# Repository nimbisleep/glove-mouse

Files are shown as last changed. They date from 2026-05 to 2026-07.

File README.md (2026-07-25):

#  Glove Mouse — Wireless Gesture-Controlled HID

**Graduation Project (Bitirme)** — Düzce University, EEE Department

A wireless glove mouse controlled by hand gestures. Uses an **ESP32** with **MPU6050 IMU (DMP)** for drift-free cursor tracking over **Bluetooth BLE**. No receiver dongle needed — pairs like any standard Bluetooth mouse.

---

##  Features

- **Drift-free cursor** — MPU6050 DMP (Digital Motion Processor) handles all orientation math on-chip. Pitch moves cursor up/down, roll moves left/right. No accumulated drift.
- **Bluetooth BLE** — ESP32 built-in BLE, pairs natively with Windows, macOS, Linux, Android
- **3 Modes:**
  - **Fix** — cursor locked in place (thumb capacitive touch)
  - **Air Tap** — capacitive trigger for click
  - **Inactive** — hand resting, no cursor movement
- **Adjustable sensitivity** — dynamic deadzone filtering
- **Custom PCB** — KiCad-designed, LTspice-validated
- **Battery-powered** — portable, wearable form factor

---

## 📁 Repository Structure

```
glove-mouse/
├── firmware/                  # ESP32 Arduino firmware
│   ├── glove_mouse_v5.ino     # Latest — DMP-based, gravity anchored
│   ├── glove_mouse_dmp.ino    # DMP firmware variant
│   ├── GloveMouse_Movement.ino
│   ├── glove_mouse_final.ino
│   ├── glove_mouse_v4.ino
│   ├── glove_mouse_v3.ino
│   └── glove_mouse_v2.ino
├── hardware/
│   └── schematics/            # KiCad PCB design files
│       ├── schematics.kicad_pcb    # PCB layout
│       ├── schematics.kicad_sch    # Schematic
│       ├── schematics.kicad_pro    # Project file
│       └── *.gbr                  # Gerber files for fabrication
└── README.md
```

---

##  Hardware

| Component | Purpose |
|---|---|
| ESP32 WROOM | Main MCU + BLE |
| MPU6050 | 6-axis IMU with DMP |
| TTP223 | Capacitive touch for click/mode |
| Flex sensors (x5) | Finger bend detection (WIP) |
| Custom PCB | KiCad-designed 2-layer board |

---

##  Firmware

The firmware uses the MPU6050's built-in DMP (Digital Motion Processor) to get stable, drift-free orientation data. The ESP32 handles BLE HID mouse reporting.

**Key firmware files:**
- `glove_mouse_v5.ino` — Latest version. Uses gravity-anchored pitch/roll, no yaw (drifts). Includes sensitivity tuning.
- `glove_mouse_dmp.ino` — DMP implementation with raw quaternion output.

### Wiring
```
MPU6050 VCC  → ESP32 3.3V
MPU6050 GND  → ESP32 GND
MPU6050 SDA  → ESP32 GPIO 21
MPU6050 SCL  → ESP32 GPIO 22
MPU6050 INT  → ESP32 GPIO 19
MPU6050 AD0  → GND
```

### Required Libraries
- `MPU6050` by ElectronicCats
- ESP32 BLE (built into ESP32 Arduino core)

---

##  PCB (KiCad)

The custom PCB is designed in KiCad as a 2-layer board:
- ESP32 footprint with all required passives
- MPU6050 IMU with I2C pull-ups and decoupling
- TTP223 capacitive touch pad
- Battery management circuit
- Breakout headers for flex sensors

Gerber files (`*.gbr`) are included for direct fabrication.

---

##  Status

| Component | Status |
|---|---|
| ✅ Movement tracking | Working via BLE |
| ✅ Click/gesture logic | Implemented |
| ✅ KiCad PCB | Designed |
| ✅ Flex sensors | Added |
| ✅ Final assembly | Glove mounting + battery |

---

##  Contact

**Salah Hussein Osman**  
saalahsega01@gmail.com

---

*Presented at Düzce University Bitirme Projeleri Sunum ve Poster Sergisi — 21 May 2026*

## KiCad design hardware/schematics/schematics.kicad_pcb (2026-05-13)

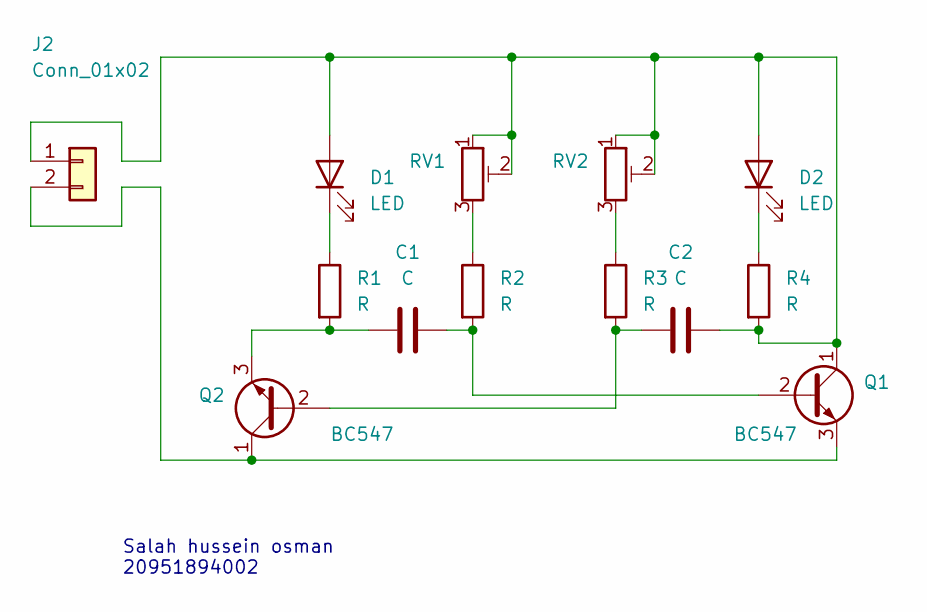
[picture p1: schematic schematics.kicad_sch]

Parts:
C1, C2: C; CP_Radial_D6.3mm_P2.50mm
D1, D2: LED; LED_D5.0mm
J2: Conn_01x02; TerminalBlock_bornier-2_P5.08mm
Q1, Q2: BC547; TO-92L_Inline_Wide
R1, R2, R3, R4: R; R_Axial_DIN0207_L6.3mm_D2.5mm_P10.16mm_Horizontal
RV1, RV2: R_Potentiometer_Trim; Potentiometer_Bourns_3386F_Vertical

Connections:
unnamed: C2.2, D1.2 (A), D2.2 (A), J2.1, Q1.1 (C), R4.2, RV1.1, RV1.2, RV2.1, RV2.2
unnamed: D1.1 (K), R1.1
unnamed: D2.1 (K), R4.1
unnamed: J2.2, Q1.3 (E), Q2.1 (C)
unnamed: C1.2, Q1.2 (B), R2.2
unnamed: C2.1, Q2.2 (B), R3.2
unnamed: C1.1, Q2.3 (E), R1.2
unnamed: R2.1, RV1.3
unnamed: R3.1, RV2.3

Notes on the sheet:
Salah hussein osman 20951894002

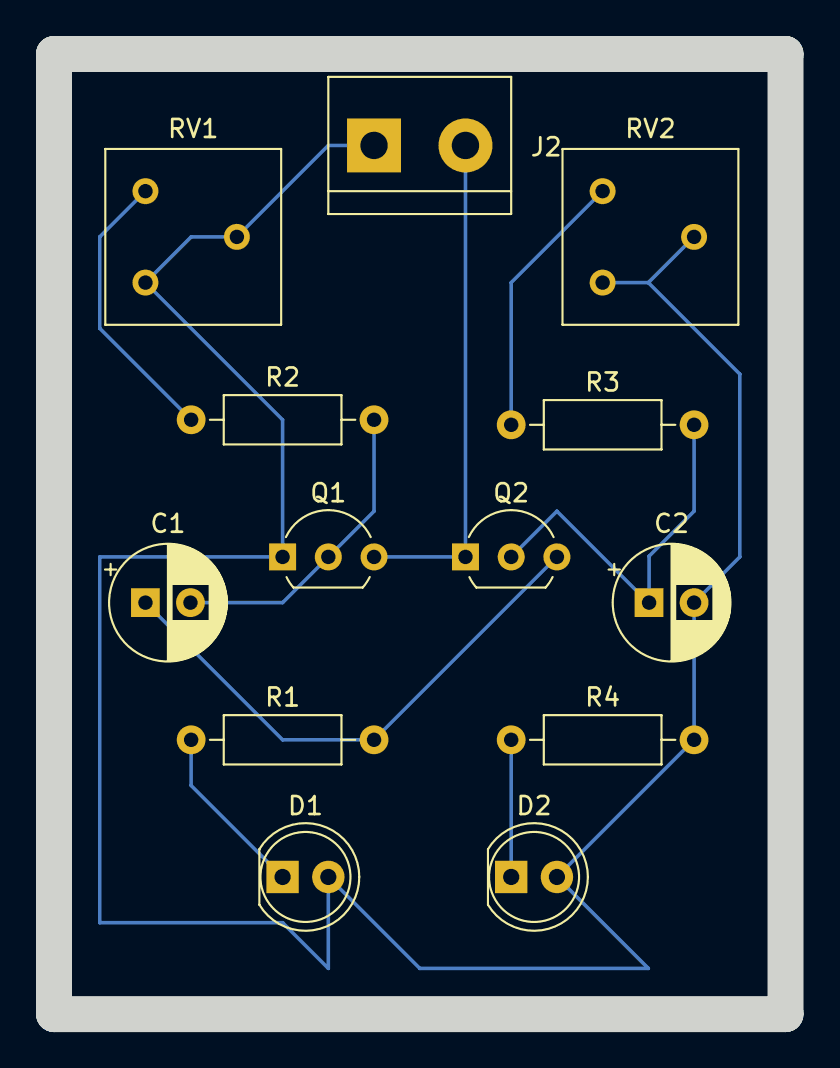
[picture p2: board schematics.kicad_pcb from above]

Board: 2 copper layers, 40.6 x 53.3 mm, 13 parts (0 on the bottom side), 9 nets.

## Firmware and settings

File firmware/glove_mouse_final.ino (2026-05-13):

/*
 * ╔══════════════════════════════════════════════════════════╗
 * ║          GLOVE MOUSE — ESP32 + MPU6050 DMP               ║
 * ║          Full build: motion + left/right click + reset   ║
 * ╚══════════════════════════════════════════════════════════╝
 *
 * WIRING:
 *   MPU6050  VCC  →  ESP32  3.3V
 *   MPU6050  GND  →  ESP32  GND
 *   MPU6050  SDA  →  ESP32  GPIO 21
 *   MPU6050  SCL  →  ESP32  GPIO 22
 *   MPU6050  INT  →  ESP32  GPIO 19
 *   MPU6050  AD0  →  GND    (sets I2C address to 0x68)
 *
 *   TTP223 #1 (LEFT CLICK)   OUT → GPIO 4  | VCC → 3.3V | GND → GND
 *   TTP223 #2 (RIGHT CLICK)  OUT → GPIO 5  | VCC → 3.3V | GND → GND
 *
 *   Both tapped simultaneously = reset cursor to center
 *
 * LIBRARIES NEEDED (install via Arduino Library Manager):
 *   1. "MPU6050" by ElectronicCats
 *   2. ESP32 BLE (built into ESP32 Arduino core)
 */

#include <Wire.h>
#include <MPU6050_6Axis_MotionApps20.h>
#include <BLEDevice.h>
#include <BLEServer.h>
#include <BLEUtils.h>
#include <BLE2902.h>
#include <BLEHIDDevice.h>
#include <HIDTypes.h>

// ─────────────────────────────────────────────────────────────────────────────
//  PIN DEFINITIONS
// ─────────────────────────────────────────────────────────────────────────────
#define SDA_PIN      21
#define SCL_PIN      22
#define MPU_INT_PIN  19
#define TOUCH_LEFT    4   // TTP223 #1 — left click
#define TOUCH_RIGHT   5   // TTP223 #2 — right click

// ─────────────────────────────────────────────────────────────────────────────
//  TUNING
// ─────────────────────────────────────────────────────────────────────────────
#define SENSITIVITY      0.5f
#define SMOOTHING        0.1f
#define COORD_MAX        4095
#define SEND_INTERVAL_MS 8

// ─────────────────────────────────────────────────────────────────────────────
//  HID DESCRIPTOR — Absolute Mouse, Report ID 1
// ─────────────────────────────────────────────────────────────────────────────
static const uint8_t hidDescriptor[] = {
  0x05, 0x01,        // Usage Page (Generic Desktop)
  0x09, 0x02,        // Usage (Mouse)
  0xA1, 0x01,        // Collection (Application)
  0x09, 0x01,        //   Usage (Pointer)
  0xA1, 0x00,        //   Collection (Physical)
  0x85, 0x01,        //     Report ID (1)
  0x05, 0x09,        //     Usage Page (Button)
  0x19, 0x01,        //     Usage Minimum (Button 1)
  0x29, 0x03,        //     Usage Maximum (Button 3)
  0x15, 0x00,        //     Logical Minimum (0)
  0x25, 0x01,        //     Logical Maximum (1)
  0x75, 0x01,        //     Report Size (1 bit)
  0x95, 0x03,        //     Report Count (3)
  0x81, 0x02,        //     Input (Data, Variable, Absolute)
  0x75, 0x05,        //     Report Size (5 bits) — padding
  0x95, 0x01,        //     Report Count (1)
  0x81, 0x03,        //     Input (Constant)
  0x05, 0x01,        //     Usage Page (Generic Desktop)
  0x09, 0x30,        //     Usage (X)
  0x09, 0x31,        //     Usage (Y)
  0x15, 0x00,        //     Logical Minimum (0)
  0x26, 0xFF, 0x0F,  //     Logical Maximum (4095)
  0x75, 0x10,        //     Report Size (16 bits)
  0x95, 0x02,        //     Report Count (2)
  0x81, 0x02,        //     Input (Data, Variable, Absolute)
  0xC0,              //   End Collection
  0xC0               // End Collection
};

// ─────────────────────────────────────────────────────────────────────────────
//  GLOBALS
// ─────────────────────────────────────────────────────────────────────────────
MPU6050 mpu;

bool     dmpReady   = false;
uint16_t packetSize = 0;
uint8_t  fifoBuffer[64];

Quaternion  q;
VectorFloat gravity;
float       ypr[3];

BLEHIDDevice*      hid   = nullptr;
BLECharacteristic* input = nullptr;
bool               bleConnected = false;

float smoothX = COORD_MAX / 2.0f;
float smoothY = COORD_MAX / 2.0f;

float yawOffset   = 0.0f;
float pitchOffset = 0.0f;
bool  offsetSet   = false;

unsigned long lastSend = 0;

// ─────────────────────────────────────────────────────────────────────────────
//  BLE CALLBACKS
// ─────────────────────────────────────────────────────────────────────────────
class ServerCallbacks : public BLEServerCallbacks {
  void onConnect(BLEServer* server) override {
    bleConnected = true;
    Serial.println("[BLE] Connected!");
  }
  void onDisconnect(BLEServer* server) override {
    bleConnected = false;
    Serial.println("[BLE] Disconnected — restarting advertising...");
    server->startAdvertising();
  }
};

// ─────────────────────────────────────────────────────────────────────────────
//  SURFACE PROJECTION
// ─────────────────────────────────────────────────────────────────────────────
void getScreenCoords(float yaw, float pitch, float &outX, float &outY) {
  float dx = cos(yaw) * cos(pitch);
  float dy = sin(yaw) * cos(pitch);
  float dz = sin(pitch);

  if (abs(dx) < 0.01f) dx = (dx >= 0) ? 0.01f : -0.01f;

  float t     = SENSITIVITY / dx;
  float projY = constrain(dy * t, -SENSITIVITY, SENSITIVITY);
  float projZ = constrain(dz * t, -SENSITIVITY, SENSITIVITY);

  outX = (projY + SENSITIVITY) / (2.0f * SENSITIVITY) * COORD_MAX;
  outY = (SENSITIVITY - projZ) / (2.0f * SENSITIVITY) * COORD_MAX;
}

// ─────────────────────────────────────────────────────────────────────────────
//  EMA
// ─────────────────────────────────────────────────────────────────────────────
inline float ema(float prev, float next, float alpha) {
  return prev + alpha * (next - prev);
}

// ─────────────────────────────────────────────────────────────────────────────
//  SEND HID REPORT
// ─────────────────────────────────────────────────────────────────────────────
void sendReport(uint8_t buttons, uint16_t x, uint16_t y) {
  uint8_t val[5] = {
    buttons,
    (uint8_t)(x & 0xFF), (uint8_t)(x >> 8),
    (uint8_t)(y & 0xFF), (uint8_t)(y >> 8)
  };
  input->setValue(val, sizeof(val));
  input->notify();
}

// ─────────────────────────────────────────────────────────────────────────────
//  SETUP
// ─────────────────────────────────────────────────────────────────────────────
void setup() {
  Serial.begin(115200);
  delay(500);
  Serial.println("\n=== Glove Mouse Boot ===");

  pinMode(TOUCH_LEFT,  INPUT);
  pinMode(TOUCH_RIGHT, INPUT);

  Wire.begin(SDA_PIN, SCL_PIN);
  Wire.setClock(400000);

  Serial.print("MPU6050 init... ");
  mpu.initialize();
  pinMode(MPU_INT_PIN, INPUT);

  if (!mpu.testConnection()) {
    Serial.println("FAILED. Check wiring!");
    while (true) delay(1000);
  }
  Serial.println("OK");

  Serial.print("DMP init... ");
  uint8_t status = mpu.dmpInitialize();
  if (status != 0) {
    Serial.printf("FAILED (code %d)\n", status);
    while (true) delay(1000);
  }

  Serial.println("OK\nCalibrating — keep glove still...");
  mpu.CalibrateAccel(6);
  mpu.CalibrateGyro(6);
  mpu.setDMPEnabled(true);
  packetSize = mpu.dmpGetFIFOPacketSize();
  dmpReady   = true;
  Serial.printf("DMP ready. Packet size: %d bytes\n", packetSize);

  Serial.print("BLE init... ");
  BLEDevice::init("GloveMouse");
  BLEServer* server = BLEDevice::createServer();
  server->setCallbacks(new ServerCallbacks());

  hid   = new BLEHIDDevice(server);
  input = hid->inputReport(1);

  hid->manufacturer()->setValue("Salah");
  hid->pnp(0x02, 0x045E, 0x0000, 0x0110);
  hid->hidInfo(0x00, 0x01);
  hid->reportMap((uint8_t*)hidDescriptor, sizeof(hidDescriptor));
  hid->startServices();

  BLEAdvertising* adv = server->getAdvertising();
  adv->setAppearance(HID_MOUSE);
  adv->addServiceUUID(hid->hidService()->getUUID());
  adv->start();

  Serial.println("OK");
  Serial.println("Advertising as 'GloveMouse'");
  Serial.println("==============================");
}

// ─────────────────────────────────────────────────────────────────────────────
//  LOOP
// ─────────────────────────────────────────────────────────────────────────────
void loop() {
  if (!dmpReady) return;
  if (!mpu.dmpGetCurrentFIFOPacket(fifoBuffer)) return;

  // ── Orientation ───────────────────────────────────────────────────────────
  mpu.dmpGetQuaternion(&q, fifoBuffer);
  mpu.dmpGetGravity(&gravity, &q);
  mpu.dmpGetYawPitchRoll(ypr, &q, &gravity);

  float yaw   = ypr[0];
  float pitch = ypr[2];

  // ── Zero on first packet ──────────────────────────────────────────────────
  if (!offsetSet) {
    yawOffset   = yaw;
    pitchOffset = pitch;
    offsetSet   = true;
    Serial.println("Yaw + Pitch zeroed.");
  }
  yaw   -= yawOffset;
  pitch -= pitchOffset;

  // ── Surface projection ────────────────────────────────────────────────────
  float rawX, rawY;
  getScreenCoords(yaw, pitch, rawX, rawY);

  // ── Smooth ────────────────────────────────────────────────────────────────
  smoothX = ema(smoothX, rawX, SMOOTHING);
  smoothY = ema(smoothY, rawY, SMOOTHING);

  uint16_t finalX = (uint16_t)constrain(smoothX, 0, COORD_MAX);
  uint16_t finalY = (uint16_t)constrain(smoothY, 0, COORD_MAX);

  // ── Touch sensors ─────────────────────────────────────────────────────────
  bool leftPressed  = digitalRead(TOUCH_LEFT);
  bool rightPressed = digitalRead(TOUCH_RIGHT);

  // Both = snap to center
  if (leftPressed && rightPressed) {
    smoothX = COORD_MAX / 2.0f;
    smoothY = COORD_MAX / 2.0f;
    finalX  = COORD_MAX / 2;
    finalY  = COORD_MAX / 2;
    Serial.println("RESET to center");
  }

  uint8_t buttons = 0;
  if (leftPressed  && !rightPressed) buttons |= 0x01;  // left click
  if (rightPressed && !leftPressed)  buttons |= 0x02;  // right click

  // ── Send ──────────────────────────────────────────────────────────────────
  unsigned long now = millis();
  if (bleConnected && (now - lastSend >= SEND_INTERVAL_MS)) {
    sendReport(buttons, finalX, finalY);
    lastSend = now;
  }

  // ── Serial debug ──────────────────────────────────────────────────────────
  Serial.printf("Yaw:%6.1f  Pitch:%6.1f  X:%4d  Y:%4d  L:%d R:%d  [%s]\n",
    degrees(yaw), degrees(pitch),
    finalX, finalY,
    leftPressed, rightPressed,
    bleConnected ? "CONN" : "----"
  );
}

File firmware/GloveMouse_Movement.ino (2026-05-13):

// ============================================================
//  GloveMouse — Movement Only (Top Tier)
//  ESP32 WROOM + MPU6050 + BLE HID
//
//  Pipeline:
//    MPU6050 raw → Madgwick 6DOF → Quaternion
//    → Pitch / Roll extraction (drift-free, gravity-anchored)
//    → Perspective projection (ray-plane)
//    → 2-axis Kalman smoother
//    → Delta → BLE HID relative mouse @ 125Hz
//
//  Required libraries (Arduino Library Manager):
//    - "ESP32 BLE Mouse"  by T-vK
//    - "MadgwickAHRS"     by x-io Technologies
//    - "MPU6050"          by Electronic Cats  (or Jeff Rowberg)
// ============================================================

#include <Wire.h>
#include <MPU6050.h>
#include <MadgwickAHRS.h>
#include <BleMouse.h>

// ─────────────────────────────────────────
//  CONFIG  —  tune these per your setup
// ─────────────────────────────────────────

// Screen resolution
#define SCREEN_W        1920
#define SCREEN_H        1080

// Field of view: how many degrees of wrist tilt = full screen width
// 60° means tilting 30° left → cursor at left edge, 30° right → right edge
#define FOV_H_DEG       60.0f
#define FOV_V_DEG       (FOV_H_DEG * (float)SCREEN_H / (float)SCREEN_W)

// Madgwick beta (0.033–0.1)
// Higher = more stable, more latency
// Lower  = more responsive, more drift
#define MADGWICK_BETA   0.05f

// Sample rate
#define SAMPLE_HZ       125
#define SAMPLE_US       (1000000 / SAMPLE_HZ)   // microseconds per frame

// Warmup: frames before sending BLE (filter convergence)
#define WARMUP_FRAMES   (SAMPLE_HZ * 2)          // 2 seconds

// Kalman measurement noise (tune per feel)
// Higher = smoother cursor, more lag
// Lower  = snappier, more jitter
#define KALMAN_R_X      4.0f
#define KALMAN_R_Y      4.0f

// Minimum pixel delta to bother sending (reduces BLE spam on still hand)
#define MOVE_THRESHOLD  1

// BLE device name
#define BLE_DEVICE_NAME "GloveMouse"


// ─────────────────────────────────────────
//  KALMAN FILTER  (1D, per axis)
// ─────────────────────────────────────────
struct Kalman1D {
    float x;        // estimate
    float p;        // error covariance
    float r;        // measurement noise
    float q;        // process noise

    Kalman1D(float measureNoise, float processNoise = 0.1f)
        : x(0), p(1), r(measureNoise), q(processNoise) {}

    float update(float z) {
        // Predict
        p += q;
        // Update
        float k = p / (p + r);
        x += k * (z - x);
        p *= (1.0f - k);
        return x;
    }

    void reset(float value) {
        x = value;
        p = 1.0f;
    }
};


// ─────────────────────────────────────────
//  GLOBALS
// ─────────────────────────────────────────
MPU6050     mpu;
Madgwick    filter;
BleMouse    bleMouse(BLE_DEVICE_NAME, "GloveLab", 100);

Kalman1D    kalX(KALMAN_R_X);
Kalman1D    kalY(KALMAN_R_Y);

// Pre-computed FOV tangent values (set in setup)
float halfTanH = 0;
float halfTanV = 0;

// Origin offset (set on warmup complete)
float originPitch = 0;
float originRoll  = 0;

// Previous smooth screen position (for delta)
float prevSX = SCREEN_W  / 2.0f;
float prevSY = SCREEN_H  / 2.0f;

// Timing
int64_t lastFrameUs = 0;

// Warmup state
int  warmupCount  = 0;
bool isWarmedUp   = false;

// Gyro calibration offsets (computed at startup)
float gyroOffX = 0, gyroOffY = 0, gyroOffZ = 0;


// ─────────────────────────────────────────
//  GYRO BIAS CALIBRATION
//  Call once at startup with sensor still
// ─────────────────────────────────────────
void calibrateGyro(int samples = 500) {
    Serial.print("Calibrating gyro");
    double sumX = 0, sumY = 0, sumZ = 0;
    for (int i = 0; i < samples; i++) {
        int16_t ax, ay, az, gx, gy, gz;
        mpu.getMotion6(&ax, &ay, &az, &gx, &gy, &gz);
        sumX += gx;
        sumY += gy;
        sumZ += gz;
        if (i % 50 == 0) Serial.print(".");
        delay(2);
    }
    gyroOffX = sumX / samples;
    gyroOffY = sumY / samples;
    gyroOffZ = sumZ / samples;
    Serial.println(" done.");
    Serial.printf("  Gyro offsets: %.1f  %.1f  %.1f\n", gyroOffX, gyroOffY, gyroOffZ);
}


// ─────────────────────────────────────────
//  SETUP
// ─────────────────────────────────────────
void setup() {
    Serial.begin(115200);
    delay(500);
    Serial.println("\n=== GloveMouse BOOT ===");

    // I2C at 400kHz
    Wire.begin();
    Wire.setClock(400000);

    // Init MPU6050
    mpu.initialize();
    if (!mpu.testConnection()) {
        Serial.println("[ERROR] MPU6050 not found! Check wiring.");
        while (true) { delay(1000); }
    }
    Serial.println("[OK] MPU6050 connected.");

    // Sensor config
    mpu.setFullScaleGyroRange(MPU6050_GYRO_FS_500);   // ±500 °/s — enough for fast wrist
    mpu.setFullScaleAccelRange(MPU6050_ACCEL_FS_2);    // ±2g
    mpu.setDLPFMode(MPU6050_DLPF_BW_42);              // 42 Hz low-pass — removes vibration noise

    // Gyro bias calibration (keep hand still for ~1s)
    calibrateGyro(500);

    // Madgwick init
    filter.begin(SAMPLE_HZ);
    filter.beta = MADGWICK_BETA;

    // Pre-compute FOV tangents
    halfTanH = tanf(FOV_H_DEG * 0.5f * DEG_TO_RAD);
    halfTanV = tanf(FOV_V_DEG * 0.5f * DEG_TO_RAD);

    // BLE HID
    bleMouse.begin();
    Serial.println("[OK] BLE advertising as \"" BLE_DEVICE_NAME "\"");
    Serial.printf("     FOV: %.0f° x %.0f°  |  Screen: %dx%d\n",
                  FOV_H_DEG, FOV_V_DEG, SCREEN_W, SCREEN_H);
    Serial.println("     Warming up filter (2s) — keep hand still...");

    lastFrameUs = esp_timer_get_time();
}
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

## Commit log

2026-05-13 Add firmware (ESP32 .ino), KiCad PCB schematics & Gerber files, update README
    [schematics-B_Cu.gbr, schematics-B_Mask.gbr, schematics-B_Paste.gbr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]
2026-07-19 Update README with flex sensors and final assembly status
